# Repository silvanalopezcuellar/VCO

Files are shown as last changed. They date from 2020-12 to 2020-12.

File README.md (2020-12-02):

# VCO

Un VCO es un circuito electrónico el cual produce una señal periódica a la salida cuya frecuencia cambia de manera proporcional al voltaje de control suministrado a la entrada del mismo. 

En el presente proyecto se presentará la concepción y diseño de un circuito VCO para la generación de tres formas de onda: seno, triangular y cuadrada, que varían dependiendo el voltaje de control a frecuencias comprendidas entre 47 a 63 Hz. En conjunto, se presentarán los parámetros claves para su implementación.

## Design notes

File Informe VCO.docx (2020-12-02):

Concepción y diseño de un VCO: Voltage Controlled Oscillator

Aguirre Angel, Adriana Andrea. Fonseca Paez, Maria Paola y López Cuéllar, Silvana.

aguirreadriana@javeriana.edu.co, fonseca_maria@javeriana.edu.co, silvana-lopez@javeriana.edu.co.

Pontificia Universidad Javeriana.

Departamento de Ingeniería Electrónica.

Resumen- En el presente documento se expone la concepción y diseño de un VCO (Voltage Controlled Oscillator), utilizado para relevar la señal de la línea en dado caso de una caída en el voltaje en la salida. El circuito se implementó en protoboard.

I. INTRODUCCIÓN

Un VCO es un circuito electrónico el cual produce una señal periódica a la salida cuya frecuencia cambia de manera proporcional al voltaje de control suministrado a la entrada del mismo.

En el presente informe se presentará la concepción y diseño de un circuito VCO para la generación de tres formas de onda: seno, triangular y cuadrada, que varían dependiendo el voltaje de control a frecuencias comprendidas entre 47 a 63 Hz. En conjunto, se presentarán los parámetros claves para su implementación.

La información contenida a continuación se dividirá en 2 items. En la primera sección se presenta una breve explicación del procedimiento de diseño teniendo en cuenta el análisis teórico del circuito utilizado, en la segunda sección se expondrán los resultados de la implementación del circuito en conjunto con una sección de conclusiones. Adicionalmente, anexo al presente informe se encuentran los cálculos teóricos requeridos para el diseño del VCO.

II. ANÁLISIS TEÓRICO

Se realizó el proceso de diseño en torno al circuito mostrado en la figura 4 (Igualmente Anexo 1).

Inicialmente se realizó el análisis el circuito de la figura 1 para obtener una señal triangular a la salida del VCO, como base para la generación de una onda seno.

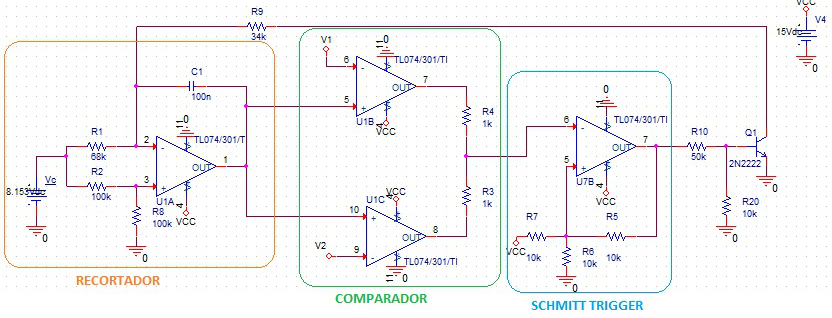
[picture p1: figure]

Figura 1. VCO con salida de señal triangular.

Para el diseño del circuito de la figura 1 se eligió como voltaje de control inicial Vc= 7.5 V y un voltaje de alimentación single supply con Vcc = 15 V. Se ingresó el voltaje de control como entrada a un circuito integrador, para generar la señal triangular por medio de la corriente sobre el condensador. Para iniciar el análisis se obtuvo el valor de la pendiente de la recta de carga del condensador, la cual se igualó a la pendiente teórica de la recta basada en su valor máximo y mínimo, obtenidos del comparador (ecuación 1). Se seleccionaron Vmax = 10 V y Vmin = 5 V con el fin de que la salida estuviera entre estos dos valores y adicionalmente se eligió un periodo inicial de 16.6 ms para una frecuencia de oscilación de 60 Hz.

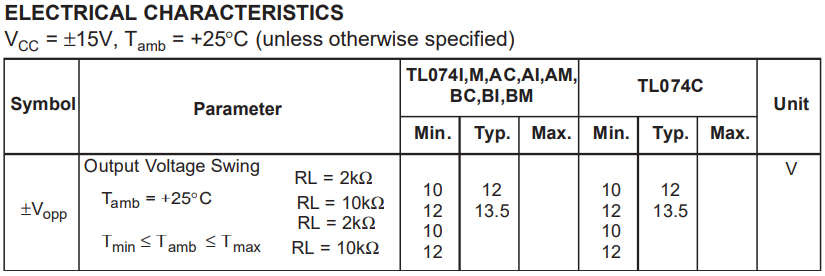
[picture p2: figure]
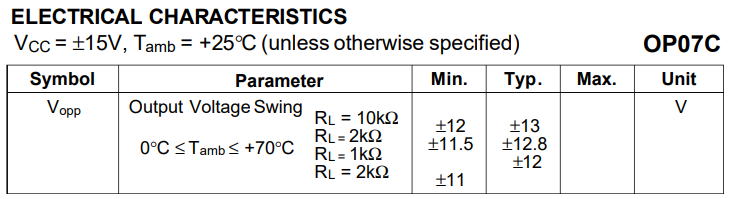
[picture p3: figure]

Tabla 1. Sección datasheet TL074 y OP07C [1][3].

Los valores de Vmax y Vmin fueron elegidos teniendo en cuenta el valor del Rail-to-rail de los OPA(Amplificadores Operacionales) seleccionados para el circuito, con el fin de evitar saturación en cualquiera de los dos extremos. El peor caso posible de voltaje de riel es para el TL074, como se muestra en la tabla 1. Para el LM324 el fabricante indica “Voltage Swing: 0V to VCC -1.5V”[2].

(1)

De la ecuación 1 y los valores máximo y mínimo elegidos, se obtuvo que R1 = 68 kΩ asumiendo un C1 = 100 nF. Luego de obtener los valores se modificó el periodo para encontrar los voltajes de control en las frecuencias entre 47 y 63 Hz y se obtuvo un mínimo de 5.99 V y un máximo de 8.11 V.

Al comparador Schmitt trigger le ingresa una señal dependiente de los comparadores entre la señal del integrador y los voltajes máximo y mínimo. Por medio de la señal de salida del comparador Schmitt trigger y de un transistor BJT en los estados de corte y saturación se obtiene en la salida del colector una señal, con la cual por medio de la resistencia de realimentación R9, se cambia el sentido de la corriente del condensador, y se cargue y descargue para obtener la señal triangular.

Después de obtener la señal triangular se utilizó el circuito de la figura 2 para obtener a la salida la señal seno.

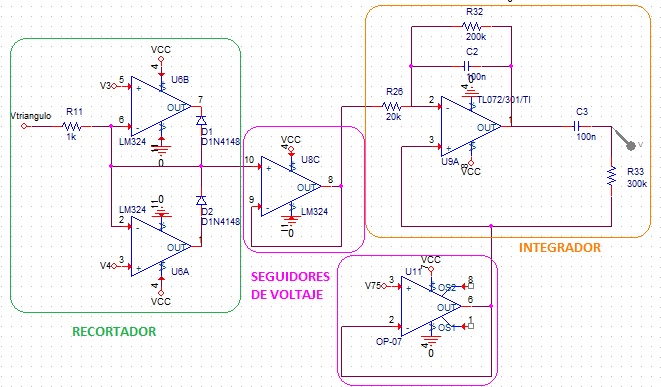
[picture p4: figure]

Figura 2. Salida seno.

Para obtener la señal seno se introdujo la señal triangular como entrada a un circuito recortador el cual se diseñó para que recortara en los voltajes V1 = 9,166 V y V2 = 5,833 V obtenidos a partir de la ecuación 3.

Luego de obtener la señal recortada, esta fue introducida en un buffer con el fin de aislar las impedancia. Esta señal se introdujo como entrada de un circuito integrador con un filtro pasa-altos a la salida referido a 7.5 V, pues al ser integrada la señal recortada, se obtuvo una señal seno centrada en 7.5 V sin ningún tipo de offset añadido por el amplificador operacional. El filtro pasa altos fue diseñado para filtrar frecuencias de una señal desde aproximadamente 5 Hz.

Para obtener los voltajes necesarios en el circuito se implementó el divisor de voltaje ilustrado en la figura 3.

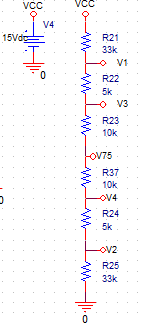
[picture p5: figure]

Figura 3. Divisor de voltaje.

Finalmente el circuito resultante se muestra en la figura 4 (Para visualizarlo mejor ver anexo).

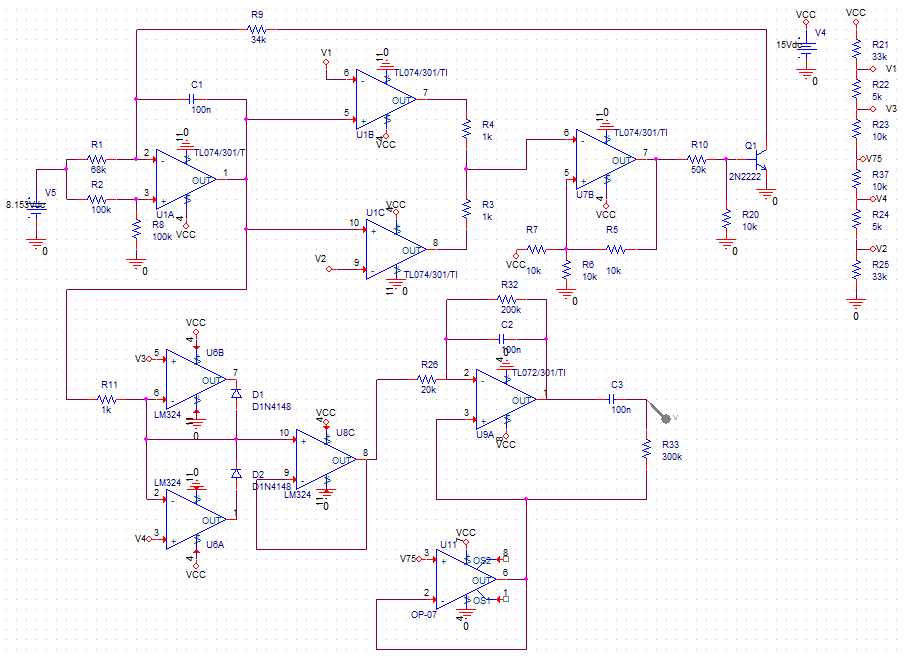
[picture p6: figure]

Figura 4. Circuito final del VCO.

Todas las simulaciones circuitales se obtuvieron por medio del programa OrCAD capture®, y todas las imágenes de la salida del circuito en el osciloscopio se obtuvieron por medio de la aplicación BenchVue®.

III. RESULTADOS EN LA IMPLEMENTACIÓN

Para la implementación se polarizó el circuito a fuente Vcc = 15 V y tierra, y se introdujo a la entrada un voltaje DC de 7,5 V el cual se varió de 5,99 V a 8,11 V para obtener las frecuencias de la señal de salida en 47 y 63 Hz respectivamente. Las salidas se observaron en el Osciloscopio Keysight InfiniVision DSO-X 2024A por medio de las puntas de prueba del mismo.

El montaje del circuito en protoboard se ilustra en la imagen 1.

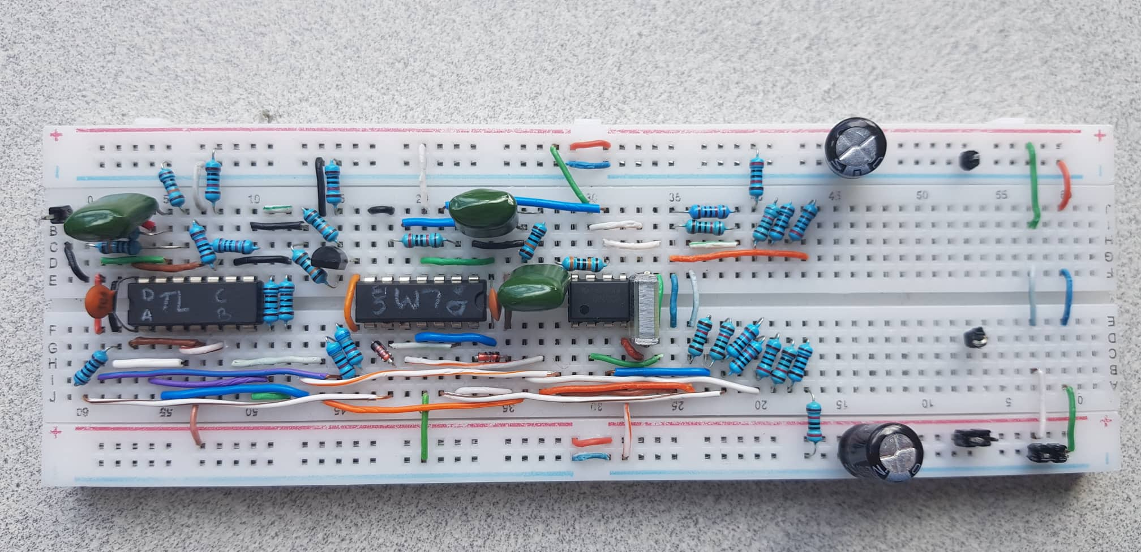
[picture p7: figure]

Imagen 1. Montaje del VCO.

En las figuras [5 y 6] se observa la señal cuadrada y la señal triangular recortada a frecuencias de 47 y 63 Hz respectivamente:

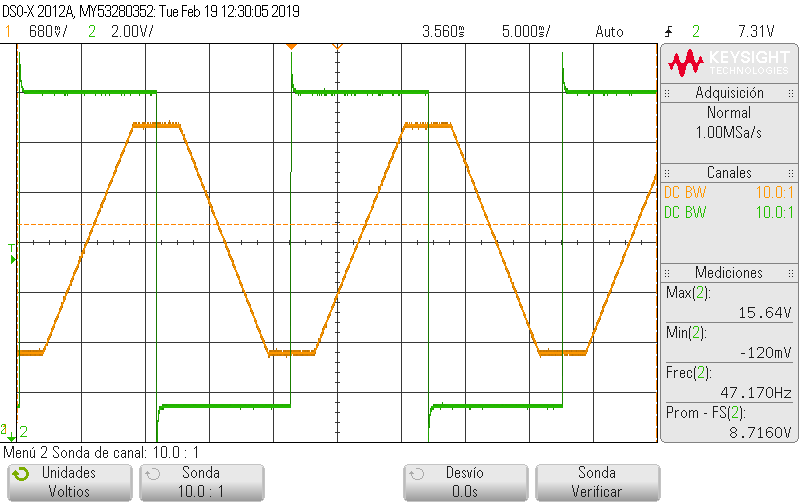
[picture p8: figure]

Figura 5. Señal triangular y señal triangular recortada a 47 Hz.

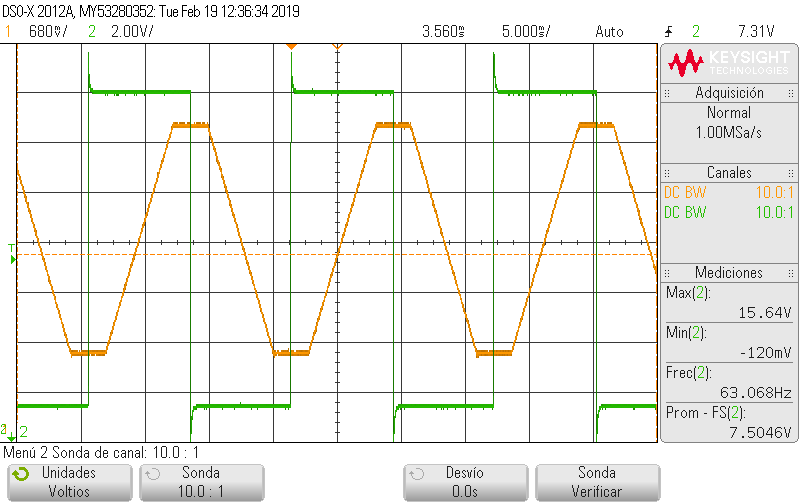
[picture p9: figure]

Figura 6. Señal triangular y señal triangular recortada a 63 Hz.

En la figura [7] se observa las señales a las salidas de los OPA que comparan contra Vmax y Vmin, para controlar el sentido de la corriente del condensador que produce la señal triángulo:

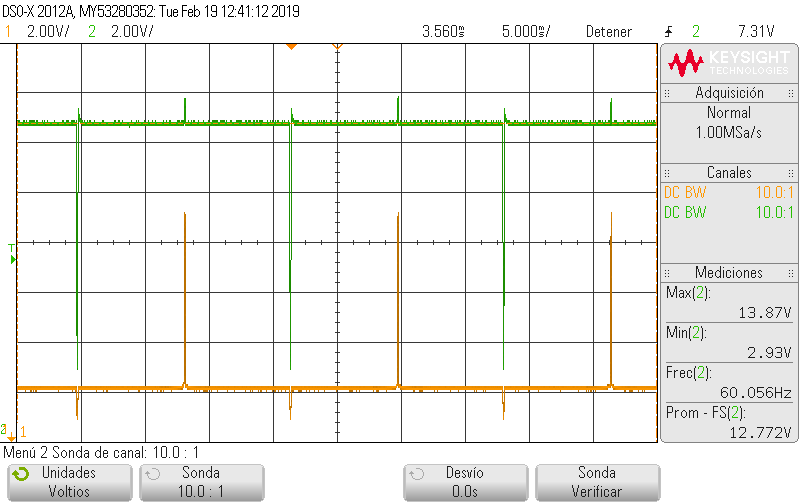
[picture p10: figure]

Figura 7. Salida de los amplificadores operacionales del primer comparador.

En las figuras [8 y 9] se observa el semiciclo positivo y negativo de la señal sinusoidal de salida respectivamente, donde se evidencia la baja distorsión (simetría y forma de onda):

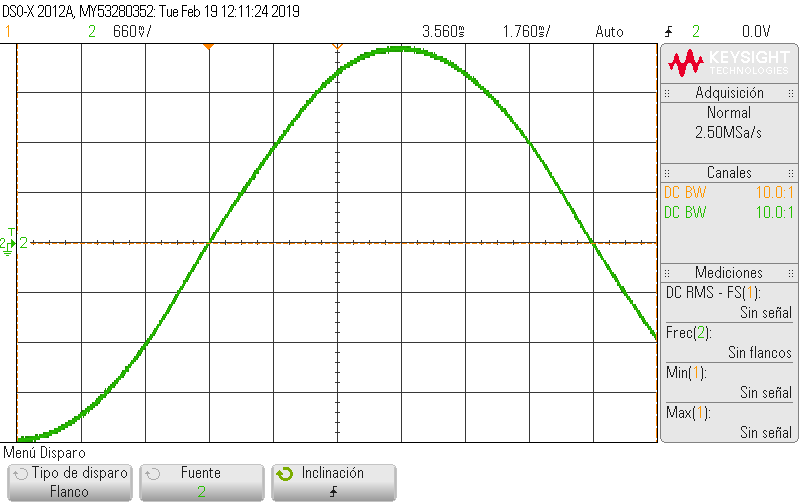
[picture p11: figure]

Figura 8. Distorsión de la señal seno en el semiciclo positivo.

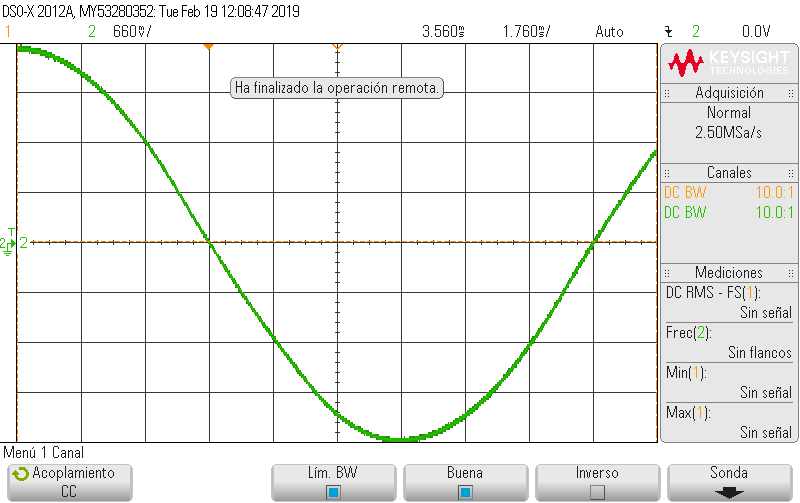
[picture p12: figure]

Figura 9. Distorsión de la señal seno en el semiciclo negativo.

En las figuras [10, 11 y 12] se observa la señal sinusoidal y la señal triangular a frecuencias de 47, 60 y 63 Hz respectivamente, y el desfase presente entre las mismas:

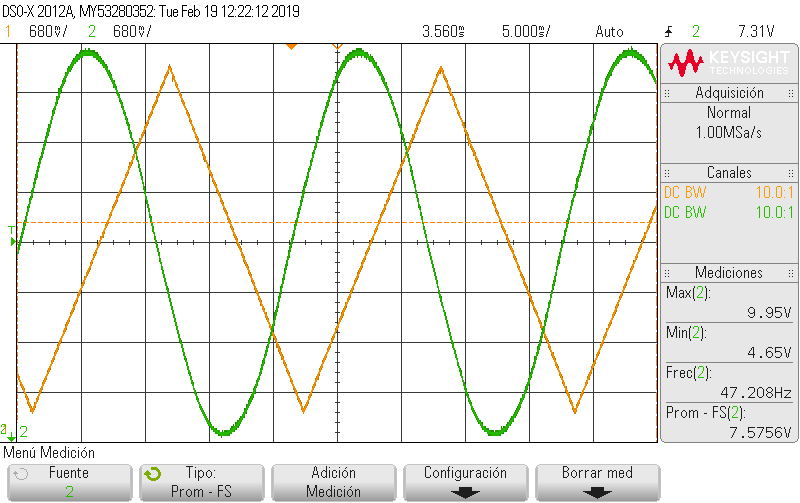
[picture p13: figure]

Figura 10. Señal triangular y señal seno a 47 Hz.

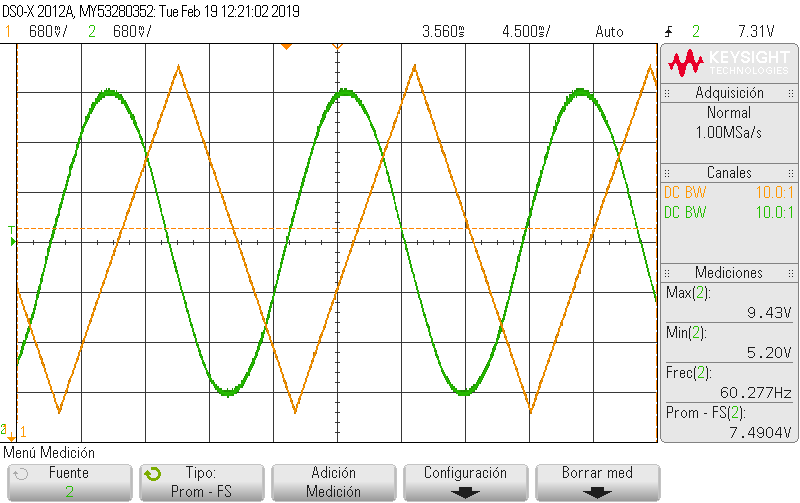
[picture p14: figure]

Figura 11. Señal triangular y señal seno a 60 Hz.

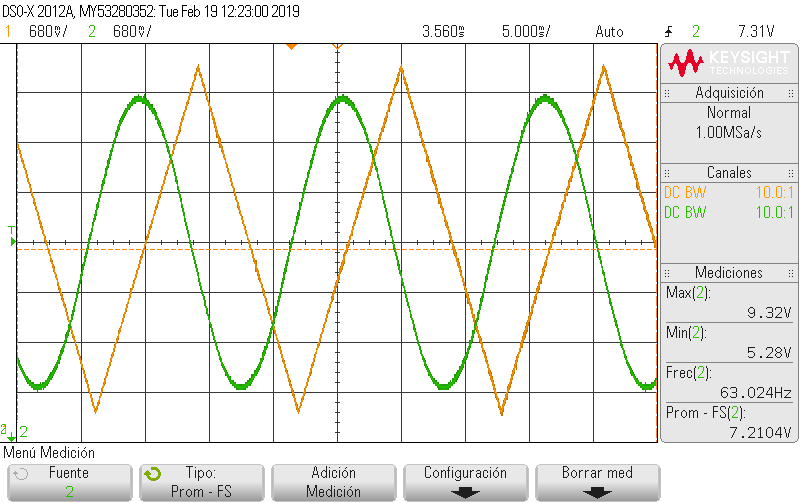
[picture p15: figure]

Figura 12. Señal triangular y señal seno a 63 Hz.

IV. CONCLUSIONES

A la salida del circuito se obtuvo una señal sinusoidal de frecuencia variable por medio del voltaje de control con baja distorsión, esto se determinó teniendo en cuenta la simetría y valores de la misma para un rango de 0 a 2π con amplitud unitaria. En π/6 y 5π/6 la señal debe valer ½, en π/3 y 2π/3 la señal debe valer √3/2, y en π/2 la señal debe valer 1 en el semiciclo positivo, y los mismos valores negativos en el semiciclo negativo. Al cumplir esto, la señal es sinusoidal y se puede considerar que posee una baja distorsión.

De los resultados obtenidos se observó que la señal de salida de salida del VCO, variaba su amplitud con los cambios del voltaje de control, lo cual es acorde al circuito que se diseñó, sin embargo para la aplicación requerida de relevar la señal de la línea en dado caso de una caída en el voltaje en la salida, es imperativo el mantenerla constante, por lo que se deberán realizar estas correcciones sobre el circuito del VCO.

V. REFERENCIAS

[1] STMicroelectronics GROUP OF COMPANIES, “TL074, TL074A - TL074B LOW NOISE J-FET QUAD OPERATIONAL AMPLIFIERS”, 2001 [Online].

Available:

http://pdf1.alldatasheet.com/datasheet-pdf/view/25382/STMICROELECTRONICS/TL074.html [Accesed 07-02-2019].

[2]Fairchild Semiconductor Corporation, “LM2902, LM324 / LM324A, LM224/ LM224A Quad Operational Amplifier”, 2002 [Online].

Available:

http://pdf1.alldatasheet.com/datasheet-pdf/view/53583/FAIRCHILD/LM324.html [Accesed 07-02-2019].

[3] STMicroelectronics GROUP OF COMPANIES, “OP07C
VERY LOW OFFSET SINGLE BIPOLAR OPERATIONAL AMPLIFIERS”, 1997 [Online].

Available:

https://pdf1.alldatasheet.com/datasheet-pdf/view/23386/STMICROELECTRONICS/OP07C.html [Accesed 07-02-2019].

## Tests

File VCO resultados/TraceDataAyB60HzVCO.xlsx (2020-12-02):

Model: | Oscilloscope DSO-X 2012A | Analog Channels
Serial Number: | MY53280352 | Sample Number | Time (s) | 1 (VOLT) | 2 (VOLT)
Address: | USBInstrument16 | 1 | -0.02140625 | 2.830654226 | 12.82411966
Date: | 2019-02-19 12:35 | 2 | -0.02135625 | 2.830654226 | 12.82411966
 |  | 3 | -0.02130625 | 2.830654226 | 12.82411966
Analog Sample Count: | 1000 | 4 | -0.02125625 | 2.911056221 | 12.82411966
 |  | 5 | -0.02120625 | 2.830654226 | 12.82411966
Setup Text Information: |  | 6 | -0.02115625 | 2.911056221 | 12.82411966
ANALOG |  | 7 | -0.02110625 | 2.911056221 | 12.82411966
Ch 1 |  | 8 | -0.02105625 | 2.830654226 | 12.82411966
Scale | 2 V/ | 9 | -0.02100625 | 2.830654226 | 12.74371766
Pos | 8.7 V | 10 | -0.02095625 | 2.830654226 | 12.82411966
Coup | DC | 11 | -0.02090625 | 2.911056221 | 12.82411966
BW | On | 12 | -0.02085625 | 2.830654226 | 12.74371766
Inv | Off | 13 | -0.02080625 | 2.830654226 | 12.82411966
Imp | 1M Ohm | 14 | -0.02075625 | 2.750252232 | 12.82411966
Probe | 10:01:00 | 15 | -0.02070625 | 2.911056221 | 12.82411966
Skew | 0 s | 16 | -0.02065625 | 2.830654226 | 12.82411966
 |  | 17 | -0.02060625 | 2.830654226 | 12.74371766
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

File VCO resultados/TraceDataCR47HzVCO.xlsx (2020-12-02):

Model: | Oscilloscope DSO-X 2012A | Analog Channels
Serial Number: | MY53280352 | Sample Number | Time (s) | 1 (VOLT) | 2 (VOLT)
Address: | USBInstrument16 | 1 | -0.02140625 | 5.984982854 | 1.407036468
Date: | 2019-02-19 12:25 | 2 | -0.02135625 | 5.984982854 | 1.407036468
 |  | 3 | -0.02130625 | 5.984982854 | 1.407036468
Analog Sample Count: | 1000 | 4 | -0.02125625 | 5.984982854 | 1.407036468
 |  | 5 | -0.02120625 | 5.984982854 | 1.407036468
Setup Text Information: |  | 6 | -0.02115625 | 5.984982854 | 14.9949735
ANALOG |  | 7 | -0.02110625 | 6.012319531 | 14.59296353
Ch 1 |  | 8 | -0.02105625 | 5.984982854 | 14.27135555
Scale | 680 mV/ | 9 | -0.02100625 | 5.984982854 | 14.27135555
Pos | 7.4885 V | 10 | -0.02095625 | 5.984982854 | 14.11055157
Coup | DC | 11 | -0.02090625 | 5.984982854 | 14.11055157
BW | On | 12 | -0.02085625 | 5.957646176 | 14.11055157
Inv | Off | 13 | -0.02080625 | 5.984982854 | 14.11055157
Imp | 1M Ohm | 14 | -0.02075625 | 5.984982854 | 14.03014957
Probe | 10:01:00 | 15 | -0.02070625 | 5.984982854 | 14.11055157
Skew | 0 s | 16 | -0.02065625 | 5.984982854 | 14.03014957
 |  | 17 | -0.02060625 | 5.984982854 | 14.03014957
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

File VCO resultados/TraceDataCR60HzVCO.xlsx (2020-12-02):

Model: | Oscilloscope DSO-X 2012A | Analog Channels
Serial Number: | MY53280352 | Sample Number | Time (s) | 1 (VOLT) | 2 (VOLT)
Address: | USBInstrument16 | 1 | -0.02140625 | 7.898550281 | 1.407036468
Date: | 2019-02-19 12:29 | 2 | -0.02135625 | 7.871213604 | 1.407036468
 |  | 3 | -0.02130625 | 7.843876926 | 1.407036468
Analog Sample Count: | 1000 | 4 | -0.02125625 | 7.816540249 | 1.407036468
 |  | 5 | -0.02120625 | 7.789203571 | 1.407036468
Setup Text Information: |  | 6 | -0.02115625 | 7.761866894 | 1.407036468
ANALOG |  | 7 | -0.02110625 | 7.734530216 | 1.407036468
Ch 1 |  | 8 | -0.02105625 | 7.707193539 | 1.487438463
Scale | 680 mV/ | 9 | -0.02100625 | 7.679856861 | 1.407036468
Pos | 7.4885 V | 10 | -0.02095625 | 7.652520183 | 1.487438463
Coup | DC | 11 | -0.02090625 | 7.597846828 | 1.487438463
BW | On | 12 | -0.02085625 | 7.597846828 | 1.407036468
Inv | Off | 13 | -0.02080625 | 7.570510151 | 1.407036468
Imp | 1M Ohm | 14 | -0.02075625 | 7.515836796 | 1.407036468
Probe | 10:01:00 | 15 | -0.02070625 | 7.515836796 | 1.407036468
Skew | 0 s | 16 | -0.02065625 | 7.488500118 | 1.487438463
 |  | 17 | -0.02060625 | 7.433826763 | 1.407036468
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

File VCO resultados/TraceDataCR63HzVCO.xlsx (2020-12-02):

Model: | Oscilloscope DSO-X 2012A | Analog Channels
Serial Number: | MY53280352 | Sample Number | Time (s) | 1 (VOLT) | 2 (VOLT)
Address: | USBInstrument16 | 1 | -0.02140625 | 8.527293865 | 1.407036468
Date: | 2019-02-19 12:31 | 2 | -0.02135625 | 8.499957187 | 1.407036468
 |  | 3 | -0.02130625 | 8.445283832 | 1.407036468
Analog Sample Count: | 1000 | 4 | -0.02125625 | 8.417947154 | 1.487438463
 |  | 5 | -0.02120625 | 8.390610477 | 1.407036468
Setup Text Information: |  | 6 | -0.02115625 | 8.363273799 | 1.487438463
ANALOG |  | 7 | -0.02110625 | 8.335937122 | 1.487438463
Ch 1 |  | 8 | -0.02105625 | 8.308600444 | 1.407036468
Scale | 680 mV/ | 9 | -0.02100625 | 8.253927089 | 1.407036468
Pos | 7.4885 V | 10 | -0.02095625 | 8.253927089 | 1.487438463
Coup | DC | 11 | -0.02090625 | 8.226590412 | 1.407036468
BW | On | 12 | -0.02085625 | 8.171917057 | 1.487438463
Inv | Off | 13 | -0.02080625 | 8.144580379 | 1.487438463
Imp | 1M Ohm | 14 | -0.02075625 | 8.117243702 | 1.407036468
Probe | 10:01:00 | 15 | -0.02070625 | 8.089907024 | 1.407036468
Skew | 0 s | 16 | -0.02065625 | 8.062570347 | 1.407036468
 |  | 17 | -0.02060625 | 8.035233669 | 1.407036468
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

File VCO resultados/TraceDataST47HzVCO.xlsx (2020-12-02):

Model: | Oscilloscope DSO-X 2012A | Analog Channels
Serial Number: | MY53280352 | Sample Number | Time (s) | 1 (VOLT) | 2 (VOLT)
Address: | USBInstrument16 | 1 | -0.02140625 | 7.871213604 | 4.704515478
Date: | 2019-02-19 12:21 | 2 | -0.02135625 | 7.871213604 | 4.704515478
 |  | 3 | -0.02130625 | 7.843876926 | 4.731852155
Analog Sample Count: | 1000 | 4 | -0.02125625 | 7.816540249 | 4.704515478
 |  | 5 | -0.02120625 | 7.789203571 | 4.704515478
Setup Text Information: |  | 6 | -0.02115625 | 7.789203571 | 4.731852155
ANALOG |  | 7 | -0.02110625 | 7.761866894 | 4.731852155
Ch 1 |  | 8 | -0.02105625 | 7.707193539 | 4.731852155
Scale | 680 mV/ | 9 | -0.02100625 | 7.707193539 | 4.731852155
Pos | 7.4885 V | 10 | -0.02095625 | 7.679856861 | 4.731852155
Coup | DC | 11 | -0.02090625 | 7.652520183 | 4.731852155
BW | On | 12 | -0.02085625 | 7.625183506 | 4.759188833
Inv | Off | 13 | -0.02080625 | 7.625183506 | 4.759188833
Imp | 1M Ohm | 14 | -0.02075625 | 7.597846828 | 4.759188833
Probe | 10:01:00 | 15 | -0.02070625 | 7.570510151 | 4.78652551
Skew | 0 s | 16 | -0.02065625 | 7.543173473 | 4.78652551
 |  | 17 | -0.02060625 | 7.515836796 | 4.78652551
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

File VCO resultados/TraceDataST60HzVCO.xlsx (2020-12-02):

Model: | Oscilloscope DSO-X 2012A | Analog Channels
Serial Number: | MY53280352 | Sample Number | Time (s) | 1 (VOLT) | 2 (VOLT)
Address: | USBInstrument16 | 1 | -0.02140625 | 8.253927089 | 5.278585706
Date: | 2019-02-19 12:20 | 2 | -0.02135625 | 8.226590412 | 5.305922383
 |  | 3 | -0.02130625 | 8.199253734 | 5.278585706
Analog Sample Count: | 1000 | 4 | -0.02125625 | 8.171917057 | 5.251249028
 |  | 5 | -0.02120625 | 8.144580379 | 5.223912351
Setup Text Information: |  | 6 | -0.02115625 | 8.089907024 | 5.278585706
ANALOG |  | 7 | -0.02110625 | 8.089907024 | 5.251249028
Ch 1 |  | 8 | -0.02105625 | 8.062570347 | 5.251249028
Scale | 680 mV/ | 9 | -0.02100625 | 8.035233669 | 5.251249028
Pos | 7.4885 V | 10 | -0.02095625 | 8.007896991 | 5.223912351
Coup | DC | 11 | -0.02090625 | 7.980560314 | 5.223912351
BW | On | 12 | -0.02085625 | 7.925886959 | 5.196575673
Inv | Off | 13 | -0.02080625 | 7.925886959 | 5.223912351
Imp | 1M Ohm | 14 | -0.02075625 | 7.871213604 | 5.223912351
Probe | 10:01:00 | 15 | -0.02070625 | 7.871213604 | 5.223912351
Skew | 0 s | 16 | -0.02065625 | 7.816540249 | 5.223912351
 |  | 17 | -0.02060625 | 7.816540249 | 5.223912351
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

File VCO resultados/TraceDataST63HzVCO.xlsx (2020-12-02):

Model: | Oscilloscope DSO-X 2012A | Analog Channels
Serial Number: | MY53280352 | Sample Number | Time (s) | 1 (VOLT) | 2 (VOLT)
Address: | USBInstrument16 | 1 | -0.02140625 | 8.855333995 | 5.715972546
Date: | 2019-02-19 12:18 | 2 | -0.02135625 | 8.827997318 | 5.688635869
 |  | 3 | -0.02130625 | 8.80066064 | 5.661299191
Analog Sample Count: | 1000 | 4 | -0.02125625 | 8.745987285 | 5.661299191
 |  | 5 | -0.02120625 | 8.718650607 | 5.633962514
Setup Text Information: |  | 6 | -0.02115625 | 8.69131393 | 5.606625836
ANALOG |  | 7 | -0.02110625 | 8.69131393 | 5.579289159
Ch 1 |  | 8 | -0.02105625 | 8.663977252 | 5.579289159
Scale | 680 mV/ | 9 | -0.02100625 | 8.609303897 | 5.551952481
Pos | 7.4885 V | 10 | -0.02095625 | 8.58196722 | 5.524615804
Coup | DC | 11 | -0.02090625 | 8.554630542 | 5.524615804
BW | On | 12 | -0.02085625 | 8.527293865 | 5.524615804
Inv | Off | 13 | -0.02080625 | 8.499957187 | 5.497279126
Imp | 1M Ohm | 14 | -0.02075625 | 8.47262051 | 5.469942449
Probe | 10:01:00 | 15 | -0.02070625 | 8.445283832 | 5.442605771
Skew | 0 s | 16 | -0.02065625 | 8.390610477 | 5.442605771
 |  | 17 | -0.02060625 | 8.363273799 | 5.415269094
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

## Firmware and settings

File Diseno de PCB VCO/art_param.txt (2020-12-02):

DEVICE-TYPE           GERBER_RS274X
OUTPUT-UNITS          MM
FILM-SIZE             24000000 16000000
FORMAT                3.2
ABORT-ON-ERROR        NO
SCALE                 1
SUPPRESS-LEAD-ZEROES  YES
SUPPRESS-TRAIL-ZEROES NO
SUPPRESS-EQUAL        YES
UNDEF-APT-CONT        NO

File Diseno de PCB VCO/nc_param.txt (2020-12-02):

INTEGER-PLACES         5
DECIMAL-PLACES         5
X-OFFSET               0.000000
Y-OFFSET               0.000000
FEEDRATE               1
COORDINATES            ABSOLUTE
OUTPUT-UNITS           METRIC
TOOL-ORDER             INCREASING
REPEAT-CODES           YES
SUPPRESS-LEAD-ZEROES   NO
SUPPRESS-TRAIL-ZEROES  YES
SUPPRESS-EQUAL         NO
TOOL-SELECT            YES
OPTIMIZE_DRILLING      YES
ENHANCED_EXCELLON      YES
HEADER                 none
LEADER                 12
CODE                   ASCII
SEPARATE               NO
SEPARATE-ROUTING       NO
DRILLING               LAYER-PAIR
BACKDRILL              NO
CAVITY                 NO
COUNTER                NO
TOLERANCE_DRILL        NO
TOLERANCE_TRAVEL       YES
TOOL_SIZE              YES
ROTATION               YES
NON_STANDARD           YES
TOTAL_DRILL            YES
SEPARATE_SLOT          YES
SUPPRESS_TOLERANCE     NO
SUPPRESS_TOOLSIZE      NO
SUPPRESS_ROTATION      YES
